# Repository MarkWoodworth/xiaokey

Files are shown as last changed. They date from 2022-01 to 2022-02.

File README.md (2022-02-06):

# xiaoKey

Even yet another electronic iambic keyer. 

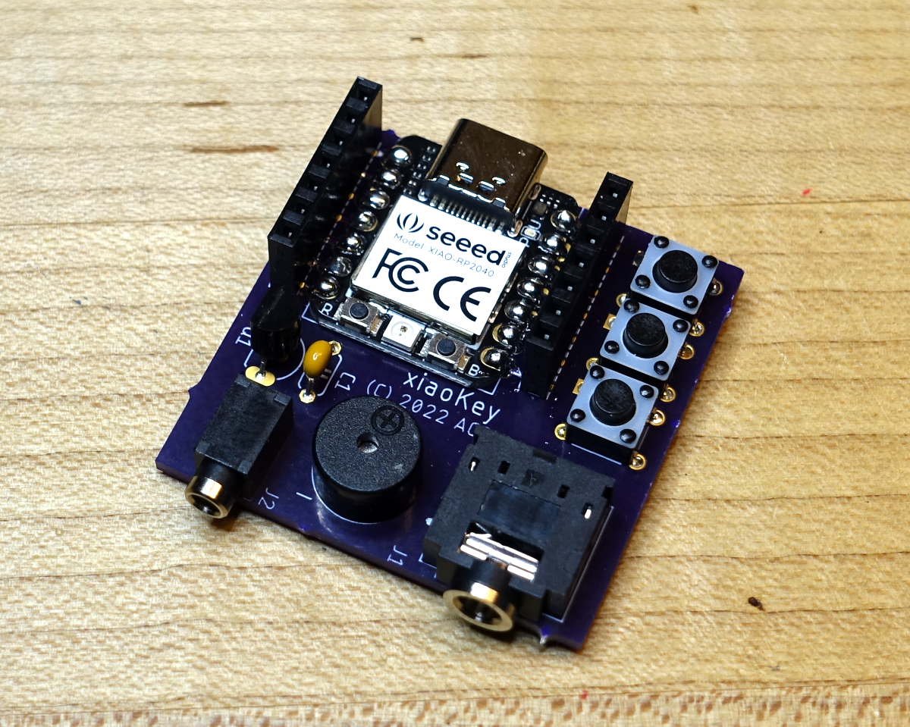
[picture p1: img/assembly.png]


It is a minimalist device based on:

* an inexpensive Seeed [Xiao](https://www.seeedstudio.com/XIAO-RP2040-v1-0-p-5026.html) RP2040 controller board
* [CircuitPython](https://circuitpython.org/) programs and libraries

The `code` directory has the files to be installed on the *Seeed Xiao* device.

The `pcb`directory has the Eagle schematics for a possible carrier board with connectors.

## Features

* Operates as an [iambic type B](http://wb9kzy.com/modeab.pdf) Morse code keyer with a 3.5mm stereo jack to connect to a dual-paddle telegraph key
* Has a configurable side tone transmitted through an on-board piezo buzzer
* Has an open-drain output to a 2.5mm mono jack, which should be able to key most radios (probably not tube sets)
* When connected to a PC over USB appears as two COM ports:
  * One is the *CircuitPython* REPL and console
  * A second port that shows the characters being transmitted, and also transmits Morse code for characters typed into the COM port
* Has three buttons to trigger canned messages
* Speed, sidetone, keyboard operation, and canned messages are configured by editing the `code.py` file on the *CIRCUITPY:* device
* Can act as a USB keyboard, where keyed characters are also sent to the computer as keystrokes.  

## Software Installation

1. Get the most recent UF2 file for *CircuitPython* on the *Xiao RP2040* [here](https://circuitpython.org/board/seeeduino_xiao_rp2040/).

2. Connect the *Xiao* to a computer using a USB C cable.

3. Follow the instructions for loading *CircuitPython* [here](https://wiki.seeedstudio.com/XIAO-RP2040-with-CircuitPython/).  Basically, you put the *Xiao* in boot loader mode by pressing and holding the _BOOT_ button and tapping the reset button.   Then copy the UF2 file to the *Xiao* which appears as `RP1-RP2`. The *Xiao* will now reboot itself.

4. Copy the required library files (in the repository `lib` directory) to the `lib` directory on the attached *Xiao*.  The files are:

   * `neopixel.mpy`
   * The directory `adafruit_hid`

   The most recent versions of these files can be found [here](https://circuitpython.org/libraries).

5. Copy `boot.py` and `code.py` to the Xiao, which now appears as drive `CIRCUITPY` on the computer.

6. Press the *RESET* button on the Xiao.

## Configuration

The device is configured by editing the source file `code.py` on the *Xiao* device.  The configuration parameters appear near the top.

```python
# user configuration
WPM = 15
SIDETONE = True
SIDEFREQ = 880
KEYBOARD = False

# user messages
MSG1 = "AC9YW"
MSG2 = "CQ CQ CQ DE AC9YW AC9YW AC9YW K"
MSG3 = "73"
```

* `SIDETONE` True will generate a tone on the buzzer when keying,  False will disable the local side tone.
* `SIDEFREQ` is the audio frequency of the side tone sound in Hz. 880 should sound like the musical note A an octave above concert A.  The frequency you choose is simply a matter of preference.
* `KEYBOARD` True will type decoded characters into the attached computers as though typed on a keyboard. *Be careful turning this on, as your Morse keying will appear in whatever window currently has focus, which can have unintended effects.*
* `MSGx` Are the contents of the canned messages triggered by the on-board tact buttons

The file `code.py` should appear as a text file on the `CIRCUITPY:` device.  There are special programs to aid in editing Python programs (such as [Mu](https://codewith.mu/) and [Thonny](https://thonny.org/)) but most simple text editors should work.  *Avoid word processing programs that save files in special formats*.   A discussion of editors for CircuitPython can be found [here](https://learn.adafruit.com/welcome-to-circuitpython/recommended-editors).

You may have to reset the Xiao after editing for the changes to take effect.

## Pinout

```
                 +---USB C--+  
  paddle dit in  D0        5V
  paddle dah in  D1       GND
      buzzer pwm D2       3v3
         key out D3       D10 in  button 1
     i2c sda     D4        D9 in  button 2 
     i2c scl     D5        D8 in  button 3
          tx     D6        D7     rx
                 +----------+
```

## Schematic

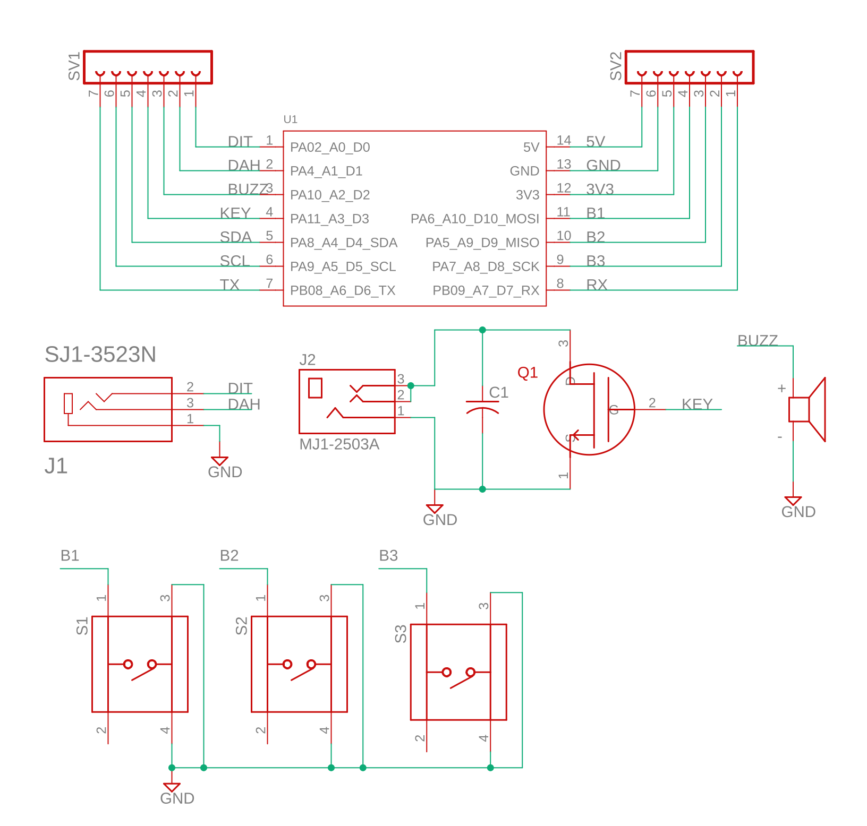
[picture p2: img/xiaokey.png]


## Bill of Materials

| Part | Description | Link |
| --- | --- | --- |
| U1 | Seeed Studio Xiao Controller RP2040 | https://www.seeedstudio.com/XIAO-RP2040-v1-0-p-5026.html |
| J1 | 3.5mm Stereo Jack | https://www.digikey.com/en/products/detail/cui-devices/SJ1-3523N/738689 |
| J2 | 2.5mm Mono jack | https://www.digikey.com/en/products/detail/cui-devices/MJ1-2503A/738679 |
| Buzz | Passive Piezo Buzzer | https://www.amazon.com/gp/product/B018I1WBNQ/ |
| Q1 | 2N7000 n-channel MOSFET 60V TO92-3  | https://www.digikey.com/en/products/detail/onsemi/2N7000-D74Z/3478161 |
| C1 | Capacitor ceramic 0.1uF 50V | https://www.digikey.com/en/products/detail/kemet/C315C103K5R5TA7303/3726109 |
| S1 S2 S3 | Tact switch SPST NO 6mm x 6mm | https://www.digikey.com/en/products/detail/cit-relay-and-switch/CT11025-0F160/12418891 |
| Headers  | Header female 7 position 0.1 pitch  | https://www.digikey.com/en/products/detail/sullins-connector-solutions/PPTC071LFBN-RC/810146 |

Most of the parts are generic:  I have given the links to where I got them.  Note that not all audio jacks are created equal:  the pin locations can vary.

## Assembly

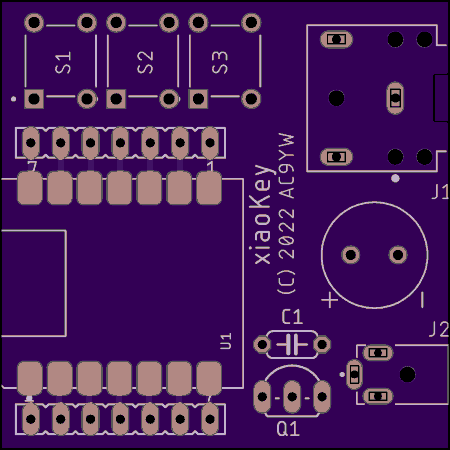
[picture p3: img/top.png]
top


The only tricky part is soldering the castellated Xiao to the board. [Here](https://learn.sparkfun.com/tutorials/how-to-solder-castellated-mounting-holes/all) is a tutorial with video on soldering castellated parts.  I think I put too much solder on the first time I tried, and filled the through holes on the Xiao.  Not a real problem, but probably not best practice.  Also, definitely solder the Xiao on first, especially before the headers!  

Not all parts are required.

* For **minimal functionality**, solder on:

  * U1 Seeed Xiao controller

  * J1 3.5mm jack to Iambic key

* To have **local side tone generation**, add:
  * 9mm piezo buzzer (note polarity)
* To **key a radio** with a sinking open drain output (up to 50V), add:
  * Q1 n-channel MOSFET transistor
  * C1 0.1 ceramic capacitor (to lessen key clicks?)
  * J2 2.5mm mono jack (open drain on tip, ground on ring)
* To **trigger stored messages**:
  * Add S1, S2, and S3 tact switches
* To allow easy access to the Xiao pins **for expansion and experimentation**:
  * Add 7 position female headers

## Future

Some Ideas:

* The I2C pins are available to expand to other parts, including a display or other inputs
* The Rx and Tx pins are available to expand to a (3.3V level) serial port

## References

The iambic keyer state machine owes a great debt to the [1keyer](https://hackaday.io/project/18841-1keyer/log/50103-state-machine-of-the-union) project by Mark VandeWettering, and the [PIK](https://owenduffy.net/module/pik/pik.htm) project by Owen Duffy.

Larry Kuck (WB7C) has very helpful resources at [Morse Code for the Radio Amateur](https://www.morsecodeclassnet.com/)

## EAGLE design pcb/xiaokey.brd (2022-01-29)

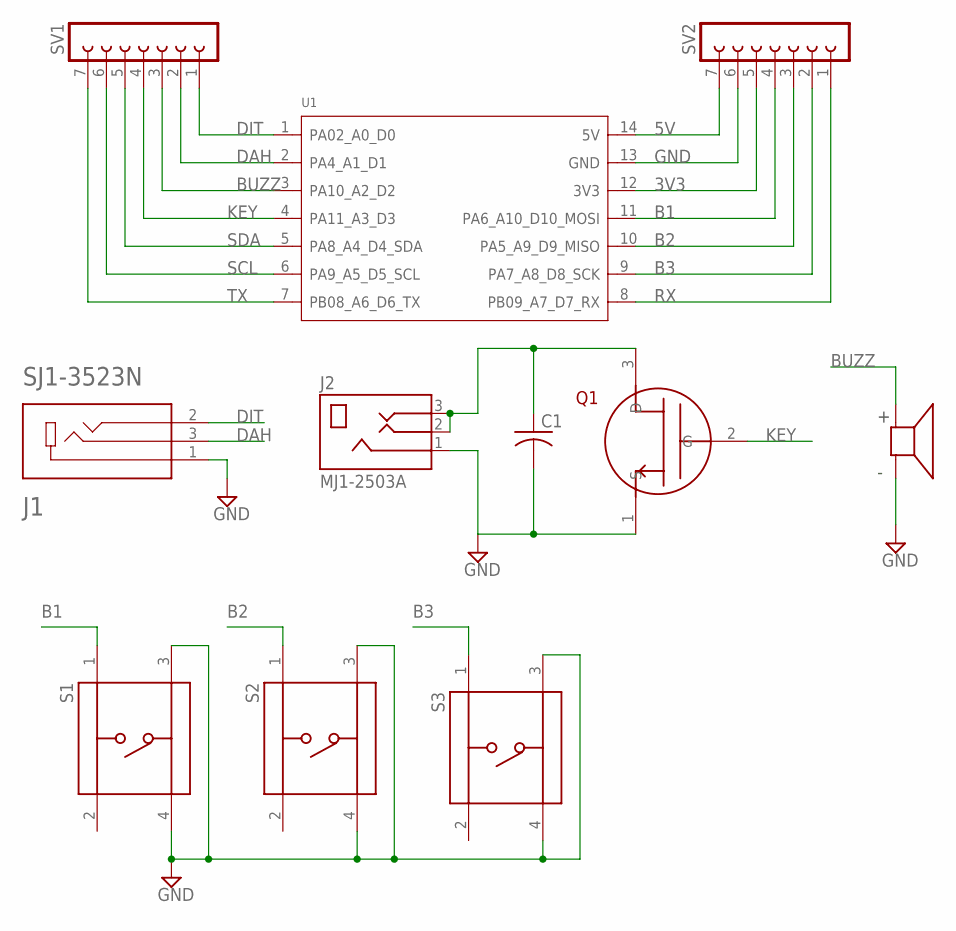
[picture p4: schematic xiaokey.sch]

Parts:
C1: C-US050-024X044; C050-024X044
J1: SJ1-3523N; CUI_SJ1-3523N
J2: MJ1-2503A; CUI_MJ1-2503A
LS1: AT-0927-TT-6-R; XDCR_AT-0927-TT-6-R
Q1: 2N7000; TO92-LINE
S1, S2, S3: TS02-66-60-BK-160-LCR-D; SW_TS02-66-60-BK-160-LCR-D
SV1, SV2: FE07-1; FE07
U1: MOUDLE-SEEEDUINO-XIAO; MOUDLE14P-2.54-21X17.8MM

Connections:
3V3: SV2.5, U1.12 (3V3)
5V: SV2.7, U1.14 (5V)
B1: S1.1, SV2.4, U1.11 (PA6_A10_D10_MOSI)
B2: S2.1, SV2.3, U1.10 (PA5_A9_D9_MISO)
B3: S3.1, SV2.2, U1.9 (PA7_A8_D8_SCK)
BUZZ: LS1.P, SV1.3, U1.3 (PA10_A2_D2)
DAH: J1.3, SV1.2, U1.2 (PA4_A1_D1)
DIT: J1.2, SV1.1, U1.1 (PA02_A0_D0)
GND: C1.2, J1.1, J2.1, LS1.N, Q1.1 (S), S1.3, S1.4, S2.3, S2.4, S3.3, S3.4, SV2.6, U1.13 (GND)
KEY: Q1.2 (G), SV1.4, U1.4 (PA11_A3_D3)
unnamed: C1.1, J2.2, J2.3, Q1.3 (D)
RX: SV2.1, U1.8 (PB09_A7_D7_RX)
SCL: SV1.6, U1.6 (PA9_A5_D5_SCL)
SDA: SV1.5, U1.5 (PA8_A4_D4_SDA)
TX: SV1.7, U1.7 (PB08_A6_D6_TX)

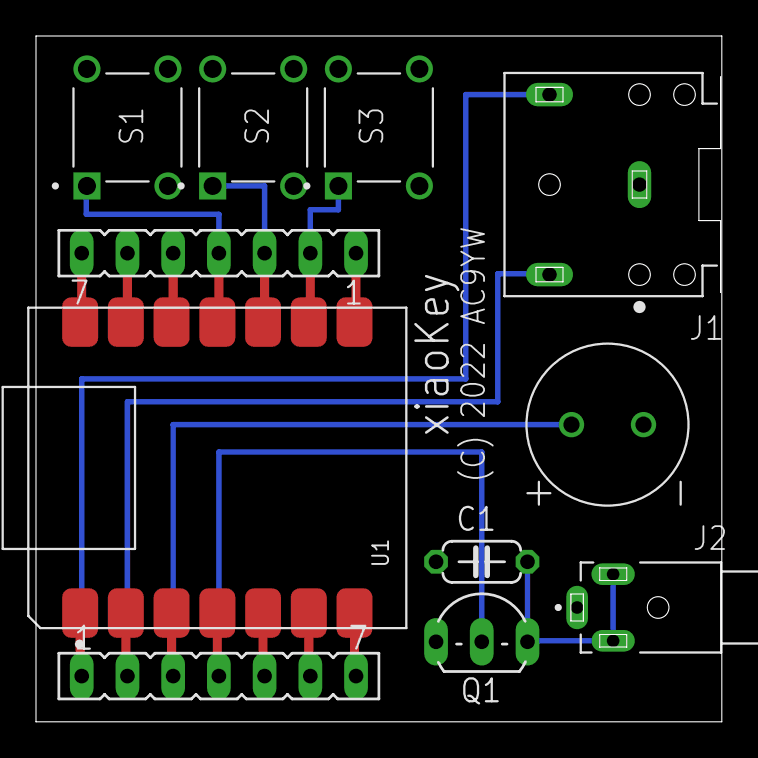
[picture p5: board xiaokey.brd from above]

Board: 2 copper layers, 38.1 x 38.1 mm, 11 parts (0 on the bottom side), 15 nets.

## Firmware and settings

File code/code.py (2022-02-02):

# xiaoKey - a computer connected iambic keyer
#
# Copyright 2022 Mark Woodworth (AC9YW)
#
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
# user configuration
WPM = 20
SIDETONE = True
SIDEFREQ = 880
KEYBOARD = False

# user messages
MSG1 = "AC9YW"
MSG2 = "CQ CQ CQ DE AC9YW AC9YW AC9YW K"
MSG3 = "73"

#               seeed xiao rp2040
#
#                 +---USB C--+  
#  paddle dit in  D0        5V
#  paddle dah in  D1       GND
#      buzzer pwm D2       3v3
#         key out D3       D10 in  button 1
#     i2c sda     D4        D9 in  button 2 
#     i2c scl     D5        D8 in  button 3
#          tx     D6        D7     rx
#                 +----------+

# imports
import time
import board
import pwmio
import neopixel
from digitalio import DigitalInOut, Direction, Pull
import usb_cdc
import usb_hid
from adafruit_hid.keyboard import Keyboard
from adafruit_hid.keyboard_layout_us import KeyboardLayoutUS
from adafruit_hid.keycode import Keycode

# setup leds (false = on)
pixel = neopixel.NeoPixel(board.NEOPIXEL,1)
red   = DigitalInOut(board.LED_RED)
red.direction = Direction.OUTPUT
red.value = True
green = DigitalInOut(board.LED_GREEN)
green.direction = Direction.OUTPUT
green.value = True
blue  = DigitalInOut(board.LED_BLUE)
blue.direction = Direction.OUTPUT
blue.value = True
def led(color):
    global red,green,blue
    red.value = True ; green.value = True ; blue.value = True
    if color=='red':  red.value   = False
    if color=='green':green.value = False
    if color=='blue': blue.value  = False

# setup buzzer (set duty cycle to ON to sound)
buzzer = pwmio.PWMOut(board.D2,variable_frequency=True)
buzzer.frequency = SIDEFREQ
OFF = 0
ON = 2**15

# setup keyer output
key = DigitalInOut(board.D3) ;
key.direction = Direction.OUTPUT

# setup paddle inputs
dit_key = DigitalInOut(board.D0)
dit_key.direction = Direction.INPUT
dit_key.pull = Pull.UP
dah_key = DigitalInOut(board.D1)
dah_key.direction = Direction.INPUT
dah_key.pull = Pull.UP

# setup push buttons
b1 = DigitalInOut(board.D10)
b1.direction = Direction.INPUT
b1.pull = Pull.UP
b2 = DigitalInOut(board.D9)
b2.direction = Direction.INPUT
b2.pull = Pull.UP
b3 = DigitalInOut(board.D8)
b3.direction = Direction.INPUT
b3.pull = Pull.UP

# setup usb serial
serial = usb_cdc.data

# setup keyboard output
time.sleep(1)  
keyboard = Keyboard(usb_hid.devices)
keyboard_layout = KeyboardLayoutUS(keyboard)

# setup encode and decode
encodings = {}
def encode(char):
    global encodings
    if char in encodings:
        return encodings[char]
    elif char.lower() in encodings:
        return encodings[char.lower()]
    else:
        return ''

decodings = {}
def decode(char):
    global decodings
    if char in decodings:
        return decodings[char]
    else:
        return '('+char+'?)'

def MAP(pattern,letter):
    decodings[pattern] = letter
    encodings[letter ] = pattern
    
MAP('.-'   ,'a') ; MAP('-...' ,'b') ; MAP('-.-.' ,'c') ; MAP('-..'  ,'d') ; MAP('.'    ,'e')
MAP('..-.' ,'f') ; MAP('--.'  ,'g') ; MAP('....' ,'h') ; MAP('..'   ,'i') ; MAP('.---' ,'j')
MAP('-.-'  ,'k') ; MAP('.-..' ,'l') ; MAP('--'   ,'m') ; MAP('-.'   ,'n') ; MAP('---'  ,'o')
MAP('.--.' ,'p') ; MAP('--.-' ,'q') ; MAP('.-.'  ,'r') ; MAP('...'  ,'s') ; MAP('-'    ,'t')
MAP('..-'  ,'u') ; MAP('...-' ,'v') ; MAP('.--'  ,'w') ; MAP('-..-' ,'x') ; MAP('-.--' ,'y')
MAP('--..' ,'z')
              
MAP('.----','1') ; MAP('..---','2') ; MAP('...--','3') ; MAP('....-','4') ; MAP('.....','5')
MAP('-....','6') ; MAP('--...','7') ; MAP('---..','8') ; MAP('----.','9') ; MAP('-----','0')

MAP('.-.-.-','.') # period
MAP('--..--',',') # comma
MAP('..--..','?') # question mark
MAP('-...-', '=') # equals, also /BT separator
MAP('-....-','-') # hyphen
MAP('-..-.', '/') # forward slash
MAP('.--.-.','@') # at sign

MAP('-.--.', '(') # /KN over to named station
MAP('.-.-.', '+') # /AR stop (end of message)
MAP('.-...', '&') # /AS wait
MAP('...-.-','|') # /SK end of contact
MAP('...-.', '*') # /SN understood
MAP('.......','#') # error

# key down and up
def cw(on):
    if on:
        key.value = True
        if SIDETONE:
           buzzer.duty_cycle = ON
        pixel.fill((0,0,30))
    else:
        key.value = False
        buzzer.duty_cycle = OFF
        pixel.fill((0,0,0))
        
# timing
def dit_time():
    global WPM
    PARIS = 50 
    return 60.0 / WPM / PARIS

# send to computer
def send(c):
#   print(c,end='')
    if serial.connected:
       serial.write(str.encode(c))
    if KEYBOARD:
        keyboard_layout.write(c)
        
# transmit pattern
def play(pattern):
    for sound in pattern:
        if sound == '.':
            cw(True)
            time.sleep(dit_time())
            cw(False)
            time.sleep(dit_time())
        elif sound == '-':
            cw(True)
            time.sleep(3*dit_time())
            cw(False)
            time.sleep(dit_time())
        elif sound == ' ':
            time.sleep(4*dit_time())
    time.sleep(2*dit_time())

# send and play message
def xmit(message):
    led('red')
    for letter in message:
        send(letter)
        play(encode(letter))
    play(' ')
    led('')
    
# send and play memories on button presses
def buttons():
    global b1, b2, b3
    if not b1.value:
        xmit(MSG1)
    if not b2.value:
        xmit(MSG2)
    if not b3.value:
        xmit(MSG3)
        
# receive, send, and play keystrokes from computer
def serials():
    if serial.connected:
        if serial.in_waiting > 0:
            led('blue') 
            letter = serial.read().decode('utf-8')
            send(letter)
            play(encode(letter))
            led('')

# decode iambic b paddles
class Iambic:
    def __init__(self,dit_key,dah_key):
        self.dit_key = dit_key
        self.dah_key = dah_key
        self.dit = False ; self.dah = False
        self.SPACE=0 ; self.DIT=1 ; self.DIT_WAIT=2 ; self.DAH=3 ; self.DAH_WAIT=4
        self.state = self.SPACE
        self.in_char = False ; self.in_word = False
        self.start = 0
        self.char = ''
    def hack(self):
        self.start = time.monotonic()
    def elapsed(self):
        return time.monotonic() - self.start
    def set_state(self, new_state):
        self.hack()
        self.state = new_state
    def latch_paddles(self):
        if not self.dit_key.value:
            self.dit = True
        if not self.dah_key.value:
            self.dah = True
    def start_dit(self):
        self.dit = False    ; self.dah = False
        self.in_char = True ; self.in_word = True
        self.char += "."
        cw(True)
        self.set_state(self.DIT)
        led('green')
    def start_dah(self):
        self.dit = False    ; self.dah = False
        self.in_char = True ; self.in_word = True
        self.char += "-"
        cw(True)
        self.set_state(self.DAH)
        led('green')
    def cycle(self):
        self.latch_paddles()
        if self.state == self.SPACE:
            if self.dit:
                self.start_dit()
            elif self.dah:
                self.start_dah()
            elif self.in_char and self.elapsed()>2*dit_time():
                self.in_char = False
                send(decode(self.char))
                self.char = ""
            elif self.in_word and self.elapsed()>6*dit_time():
                self.in_word = False
                send(" ")
                led('')
        elif self.state == self.DIT:
            if self.elapsed() > dit_time():
                cw(False)
                self.dit = False
                self.set_state(self.DIT_WAIT)
        elif self.state == self.DIT_WAIT:
            if self.elapsed() > dit_time():
                if self.dah:
                    self.start_dah()
                elif self.dit:
                    self.start_dit()
                else:
                    self.set_state(self.SPACE)
        elif self.state == self.DAH:
            if self.elapsed() > 3*dit_time():
                cw(False)
                self.dah = False
                self.set_state(self.DAH_WAIT)
        elif self.state == self.DAH_WAIT:
            if self.elapsed() > dit_time():
                if self.dit:
                    self.start_dit()
                elif self.dah:
                    self.start_dah()
                else:
                    self.set_state(self.SPACE)              

# paddle instance
iambic = Iambic(dit_key,dah_key)

# run
while True:
    buttons()
    serials()
    iambic.cycle()          

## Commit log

2022-01-27 added MIT license, changed led usage
2022-01-29 re-arranged directories, added pcb files, renamed keyer.py
    [xiaokey.brd, xiaokey.sch]
2022-01-29 added schematic
2022-01-29 added pcb image
2022-02-02 added assembly photo
2022-02-02 swapped dit and dah inputs
    [code.py]
2022-02-05 added BOM and notes to README

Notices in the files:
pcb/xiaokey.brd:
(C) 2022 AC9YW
